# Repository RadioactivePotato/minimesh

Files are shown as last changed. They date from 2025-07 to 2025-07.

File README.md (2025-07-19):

# minimesh
A tiny, low-power Meshtastic compatible device with GPS, enviroment sensor and an OLED display powered by nRF52840

# About

I made this because I found that alot of pre-made Meshtastic nodes are too big and too power hungry, this node uses the nRF52840 chip instead of the ESP32-S3 since it's much more power efficient, while only sacrificing the Wi-Fi feature.

# Images

<details>
<summary>Schematic (click to expand)</summary>

| Schematic |
|-----------|
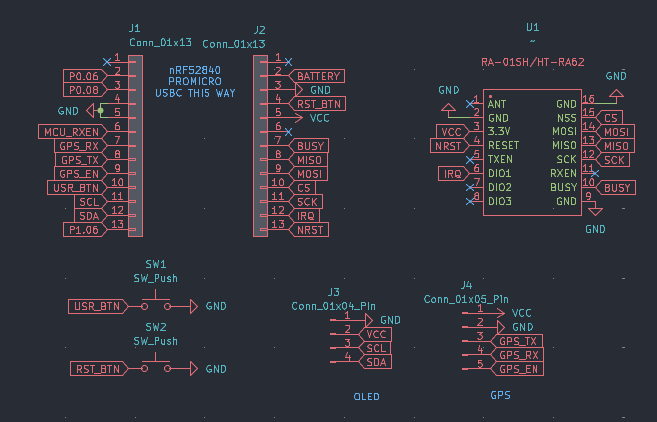
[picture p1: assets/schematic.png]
Schematic
|  |

</details>

| PCB | 3D Preview | Case |
|-----|---|---|
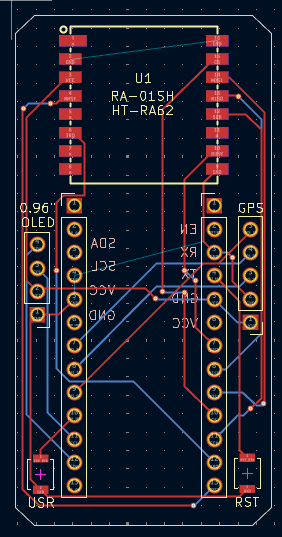
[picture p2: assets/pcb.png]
PCB
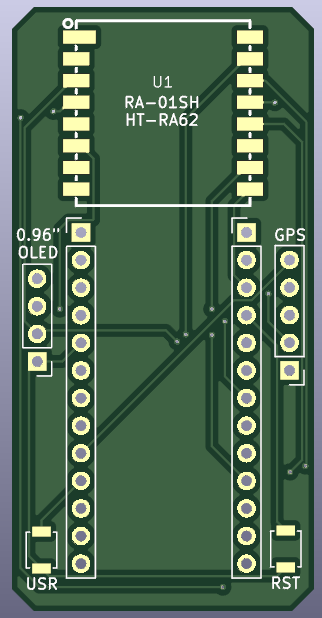
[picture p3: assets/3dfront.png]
3D-Front
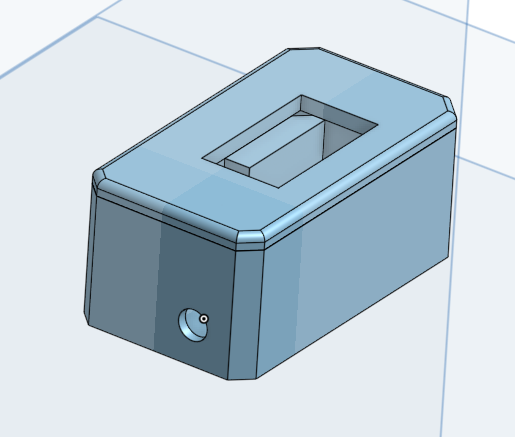
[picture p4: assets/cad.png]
Baseplate
|  |  |  |
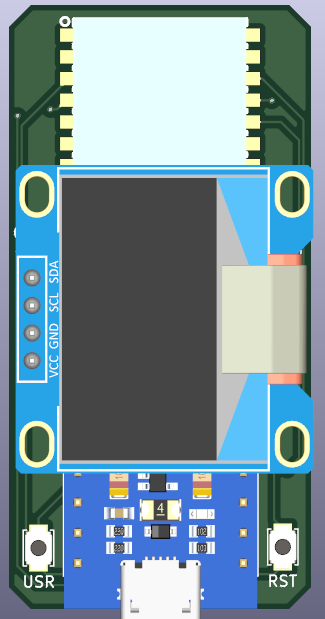
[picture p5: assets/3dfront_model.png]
3D-Front(Model)
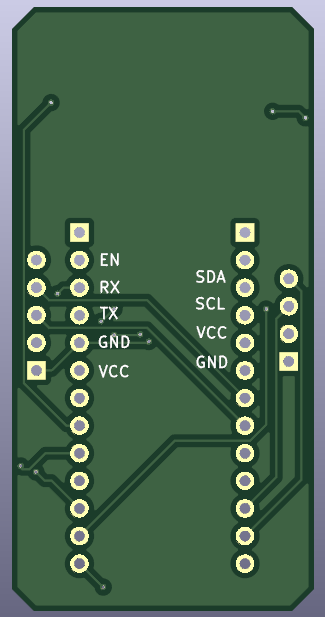
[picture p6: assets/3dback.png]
3D-Back
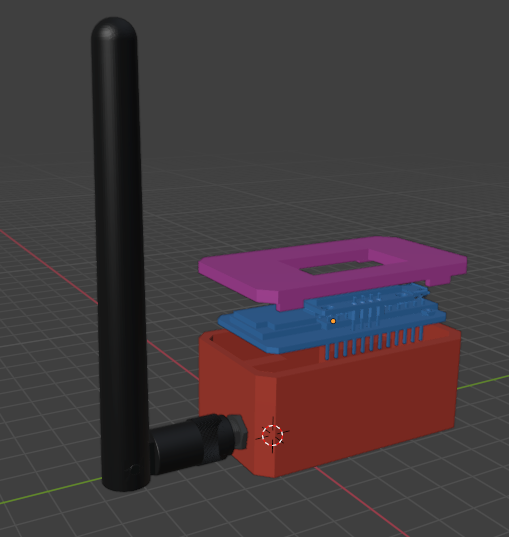
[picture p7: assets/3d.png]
3D
|  |  |  |

# BOM

| Qty | Item | Notes | Cost (USD) | URL |
|-----|---|---|---|-----|
| 2 | nRF52840 ProMicro | MCU (incl vat+shipping) | 8.16 | [AliExpress](https://www.aliexpress.com/item/1005006446457448.html) |
| 2 | HT-RA62 Transceiver Module | Can be replaced with RA-01SH  | 15.63 | [AliExpress](https://www.aliexpress.com/item/1005005543917617.html) |
| 2 | 0.96" OLED Display | Pinout needs to be GND,VCC... | 4.36 | [AliExpress](https://www.aliexpress.com/item/1005008738379315.html) |
| 4 | Switches | | 0.99 | [AliExpress](https://www.aliexpress.com/item/4001125532910.html) |
| 2 | GP-02-KIT GPS Module | | 11.44 | [AliExpress](https://www.aliexpress.com/item/1005008346885630.html) |
| 2 | Slide Switch | For GPS module (5mm) | 1.64 | [AliExpress](https://www.aliexpress.com/item/1005007162182882.html) |
| 2 | 868MHz antenna (SMA M) | | 12.60 | [AliExpress](https://www.aliexpress.com/item/1005006712636707.html) |
| 2 | BME280 Module | Telementary data | 5.96 | [AliExpress](https://www.aliexpress.com/item/1005008511564094.html) |
| 2 | 3.7V BMS Board | Prevent overcharging/discharging | 1.32 | [AliExpress](https://www.aliexpress.com/item/1005008760086623.html) |
| 2 | Battery Connector | | 0.67 | [AliExpress](https://www.aliexpress.com/item/1005002564191148.html) |
|-----|---------------------------------|-------------------------------|------------|-----|
| 5 | PCB | Min order qty - 5 | 1.50 | JLCPCB |
|-----|---------------------------------|-------------------------------|------------|-----|
|-----|---------------------------------|-------------------------------| 64.29USD |-----|

A badge of a Cerberus and a raccoon laughing together, with the text "HIGHWAY" and "HACK CLUB" beside them.

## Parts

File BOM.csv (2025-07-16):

Qty | Item | Notes | Cost (GBP) | URL
2 | HT-RA62 Transceiver Module | Can be replaced with RA-01SH | 13.18 | https://www.aliexpress.com/item/1005005543917617.html
2 | nRF52840 ProMicro | MCU (incl vat+shipping) | 10.46 | https://www.elecrow.com/pro-micro-nrf52840-development-board-compatible-with-nice-nano-v2-0.html
2 | 0.96" OLED Display |  | 3.64 | https://www.aliexpress.com/item/1005008738379315.html
4 | Switches |  | 2.64 | https://www.aliexpress.com/item/4001125532910.html
2 | GP-02-KIT GPS Module |  | 6.7 | https://www.aliexpress.com/item/1005008346885630.html
2 | Slide Switch | For GPS module (5mm) | 2.74 | https://www.aliexpress.com/item/1005007162182882.html
2 | 868MHz antenna (SMA M) |  | 9.04 | https://www.aliexpress.com/item/1005006712636707.html
2 | BME280 Module | Telementary data | 1.52 | https://www.aliexpress.com/item/1005008511564094.html
5 | PCB | Min order qty - 5 | 1.11 | JLCPCB
 |  |  | 51.03GBP
 |  |  | 68.43USD

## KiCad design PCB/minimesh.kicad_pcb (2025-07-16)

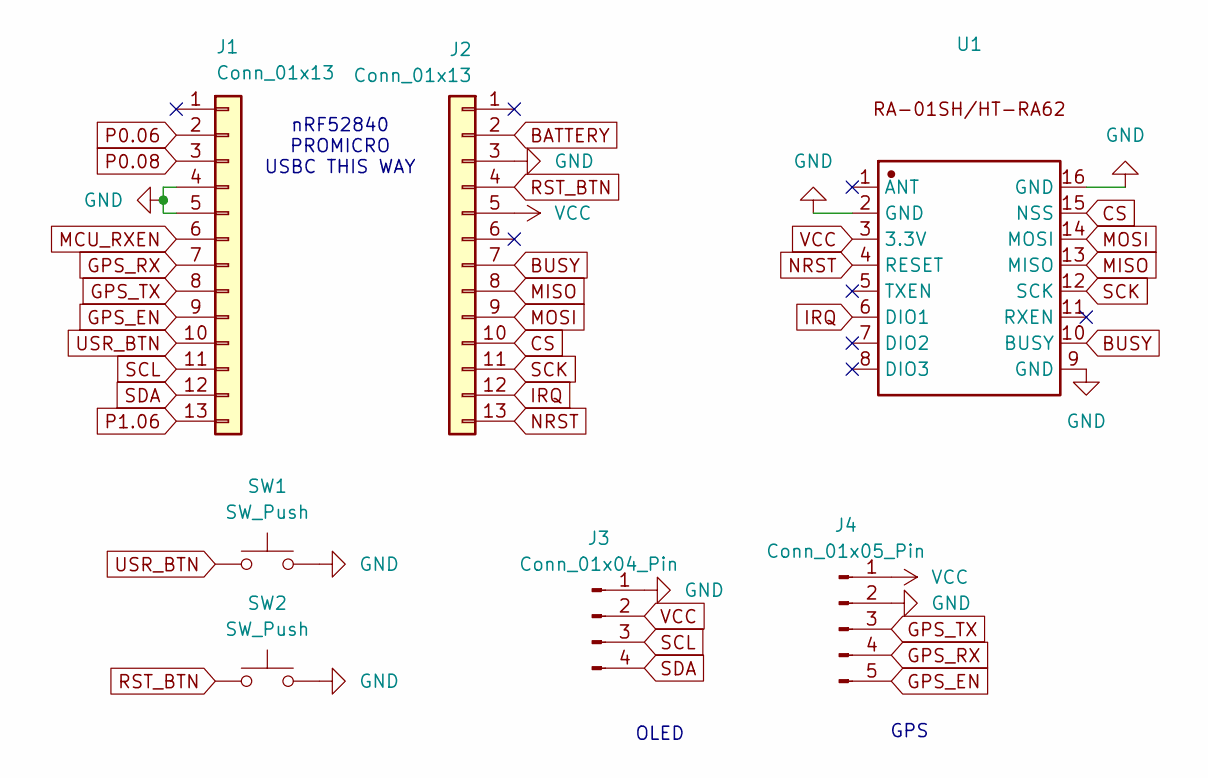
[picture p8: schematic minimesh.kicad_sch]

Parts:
J1, J2: Conn_01x13; PinHeader_1x13_P2.54mm_Vertical
J3: Conn_01x04_Pin; PinHeader_1x04_P2.54mm_Vertical
J4: Conn_01x05_Pin; PinHeader_1x05_P2.54mm_Vertical
SW1, SW2: SW_Push; SW_SPST_B3U-1000P
U1: RA-01SH

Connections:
BATTERY: J2.2
BUSY: J2.7, U1.10 (BUSY)
CS: J2.10, U1.15 (NSS)
GND: J1.4, J1.5, J2.3, J3.1, J4.2, SW1.2, SW2.2, U1.2 (GND), U1.9 (GND), U1.16 (GND)
GPS_EN: J1.9, J4.5
GPS_RX: J1.7, J4.4
GPS_TX: J1.8, J4.3
IRQ: J2.12, U1.6 (DIO1)
MCU_RXEN: J1.6
MISO: J2.8, U1.13 (MISO)
MOSI: J2.9, U1.14 (MOSI)
NRST: J2.13, U1.4 (RESET)
P0.06: J1.2
P0.08: J1.3
P1.06: J1.13
RST_BTN: J2.4, SW2.1
SCK: J2.11, U1.12 (SCK)
SCL: J1.11, J3.3
SDA: J1.12, J3.4
USR_BTN: J1.10, SW1.1
VCC: J2.5, J3.2, J4.1, U1.3 (3.3V)

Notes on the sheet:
OLED
GPS
nRF52840 PROMICRO USBC THIS WAY

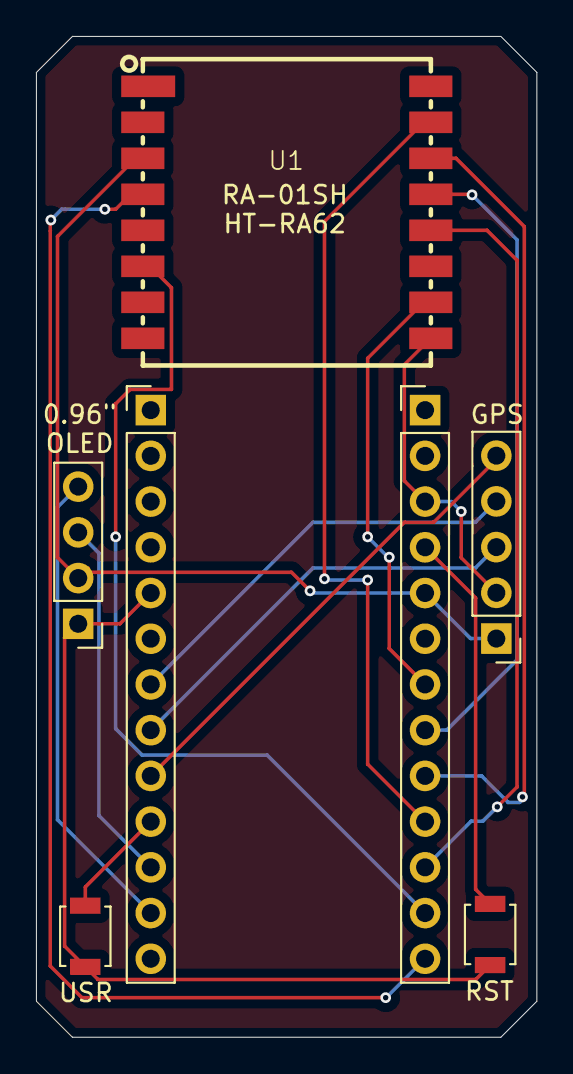
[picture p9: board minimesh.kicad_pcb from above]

Board: 2 copper layers, 27.8 x 55.6 mm, 7 parts (0 on the bottom side), 16 nets.

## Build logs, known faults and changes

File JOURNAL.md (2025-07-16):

---
title: "MiniMesh"
author: "krunch"
description: "A tiny, low-power Meshtastic compatible device with GPS, enviroment sensor and an OLED display powered by nRF52840"
created_at: "2025-07-10"
---

# July 12 - Schematic (2 hours)

I made the schematic today, I wanted a low-power device so I went with the nRF52840, it only uses around 10mA on average so it's perfect since this device would spent alot of time on battery power.

For the RF trasnceiver, I chose the HT-RA62, it uses the SX1262 chip which is widely supported by the Meshtastic firmware.

For the OLED display, I chose one that uses SSD1306 drivers, these are plug and play with the Meshtastic firmware.



Tomorrow, I will see if I can integrate a on-board GPS chip.

# July 13 - Layout and Wiring (1.5 hours)

Today I did the PCB layout, since I wanted this PCB to be as small as possible, I made it so that the OLED sits on top of the pro micro like this



I also quickly made a model of the radio transceiver in OnShape since I couldn't find one.

| 3D Model | Real |
|---|---|
|  |  |

And then I wired everything up, I managed to slip a few traces on the edge of the board

This took quite a while but I managed to make it look good






I'm going model the case tomorrow!

# July 16 - Case Design (2 hours)

Today I made the case, the case will be printed in 2 parts, the base and the lid



I added a hole for the IPEX/u.FL to SMA connector to screw into (for the antenna)



The PCB will sit ontop of the platforms inside the case



And the lid will clip into place to the base

To design the case, I imported a refrence image and drew around it, the GPS module and the BME280 module will sit at the bottom, and the wires will run up through the side.





This is what the case looks like with the antenna installed,

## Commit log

2025-07-12 bom update
2025-07-13 updated bom
2025-07-16 july 16 case design
2025-07-16 repo setup
    [minimesh.kicad_pcb, minimesh.kicad_sch]
2025-07-16 changed bom to 2 units since a mesh is 2+ nodes
2025-07-16 added more images
    [BOM.csv]
